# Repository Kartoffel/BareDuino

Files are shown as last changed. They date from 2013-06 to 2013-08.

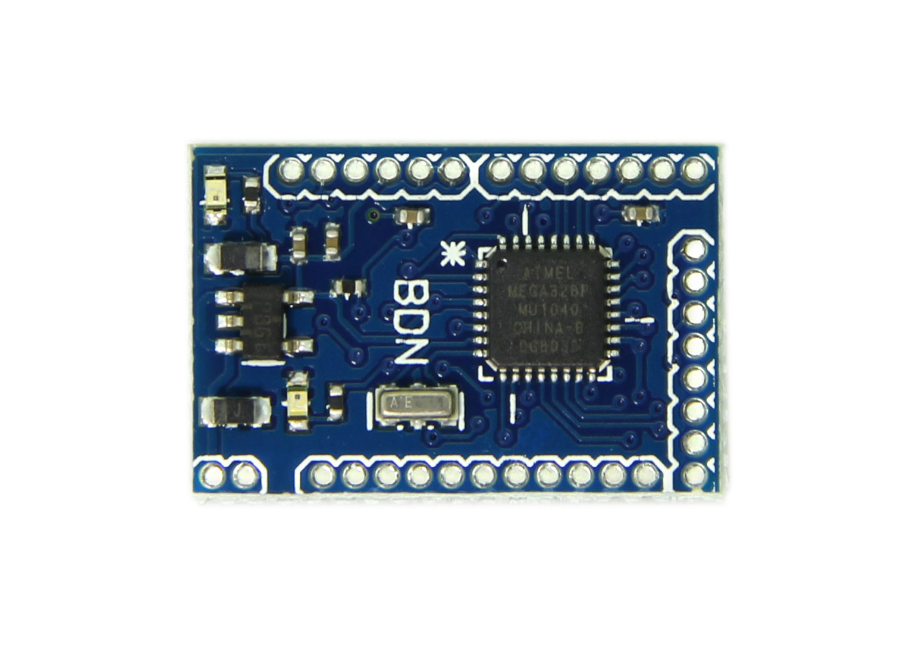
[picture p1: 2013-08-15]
Nano/pictures/IMG_1922.jpg

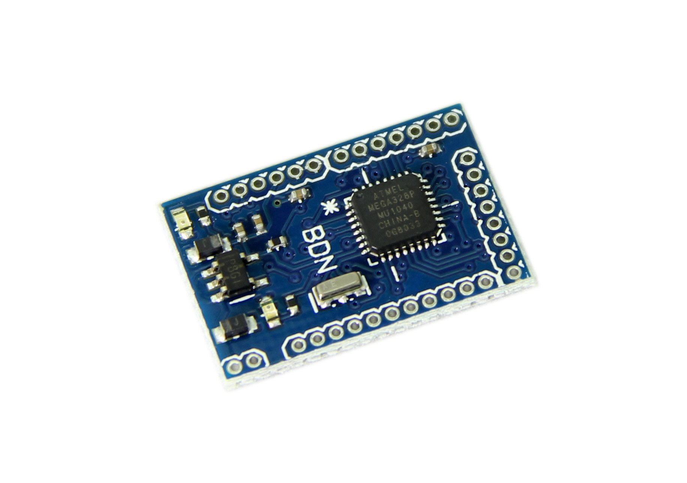
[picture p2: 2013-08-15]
Nano/pictures/IMG_1902.jpg

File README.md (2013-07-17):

BareDuino
===============
This repository contains the design (and other relevant) files for all the released BareDuino's.
Please visit this website for more information ----> http://www.niekproductions.com/

## License ##
All of the files in this repository are released under the BSD license.
Copyright (c) NiekProductions, 2013 All rights reserved.

Redistribution and use in source and binary forms, with or without modification, are permitted provided that the following conditions are met:
Redistributions of source code must retain the above copyright notice, this list of conditions and the following disclaimer. Redistributions in binary form must reproduce the above copyright notice, this list of conditions and the following disclaimer in the documentation and/or other materials provided with the distribution. THIS SOFTWARE IS PROVIDED BY THE COPYRIGHT HOLDERS AND CONTRIBUTORS "AS IS" AND ANY EXPRESS OR IMPLIED WARRANTIES, INCLUDING, BUT NOT LIMITED TO, THE IMPLIED WARRANTIES OF MERCHANTABILITY AND FITNESS FOR A PARTICULAR PURPOSE ARE DISCLAIMED. IN NO EVENT SHALL THE COPYRIGHT HOLDER OR CONTRIBUTORS BE LIABLE FOR ANY DIRECT, INDIRECT, INCIDENTAL, SPECIAL, EXEMPLARY, OR CONSEQUENTIAL DAMAGES (INCLUDING, BUT NOT LIMITED TO, PROCUREMENT OF SUBSTITUTE GOODS OR SERVICES; LOSS OF USE, DATA, OR PROFITS; OR BUSINESS INTERRUPTION) HOWEVER CAUSED AND ON ANY THEORY OF LIABILITY, WHETHER IN CONTRACT, STRICT LIABILITY, OR TORT (INCLUDING NEGLIGENCE OR OTHERWISE) ARISING IN ANY WAY OUT OF THE USE OF THIS SOFTWARE, EVEN IF ADVISED OF THE POSSIBILITY OF SUCH DAMAGE.

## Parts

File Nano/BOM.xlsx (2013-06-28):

BareDuino Nano v2 BOM
Prices are per item, bulk may be cheaper
Qty | Total Qty | Value | Device | Parts | Mouser Part# | Price per part | Total Price
4 | 4 | 0.1uF | C-EUC0402K | C1, C2, C3, C6 | 80-C0402C104K4P | $0.06 | $0.26
1 | 1 | 10K | R-EU_R0402 | R2 | 667-ERJ-2GEJ103X | $0.05 | $0.05
2 | 2 | 10uF | C-USC0603K | C4, C7 | 71-298D106X06R3M2T | $1.27 | $2.54
1 | 1 | 16Mhz | RESONATORSMD | Y1 | 81-CSTCE16M0V53-R0 | $0.93 | $0.93
2 | 2 | 330 | R-EU_R0402 | R1, R3 | 667-ERJ-2GEJ331X | $0.05 | $0.10
1 | 1 | ATMEGA328P-MU | ATMEGA328P-MU | UC1 | 556-ATMEGA328P-MU | $5.44 | $5.44
1 | 1 | Orange | LED0603 | LED2 | 720-LOQ976-PS-25 | $0.11 | $0.11
1 | 1 | Green | LED0603 | LED1 | 645-598-8070-107F | $0.09 | $0.09
1 | 1 | MIC5205 / other | V_REG_LDOSMD | U1 | 595-TPS76350DBVR | $1.02 | $1.02
Boards: | 1 |  |  |  | Total per board: |  | $10.54
 |  |  |  |  | Total excluding shipping: |  | $10.54
 |  |  |  |  | Shipping: |  | $0.00
 |  |  |  |  | Total: |  | $10.54

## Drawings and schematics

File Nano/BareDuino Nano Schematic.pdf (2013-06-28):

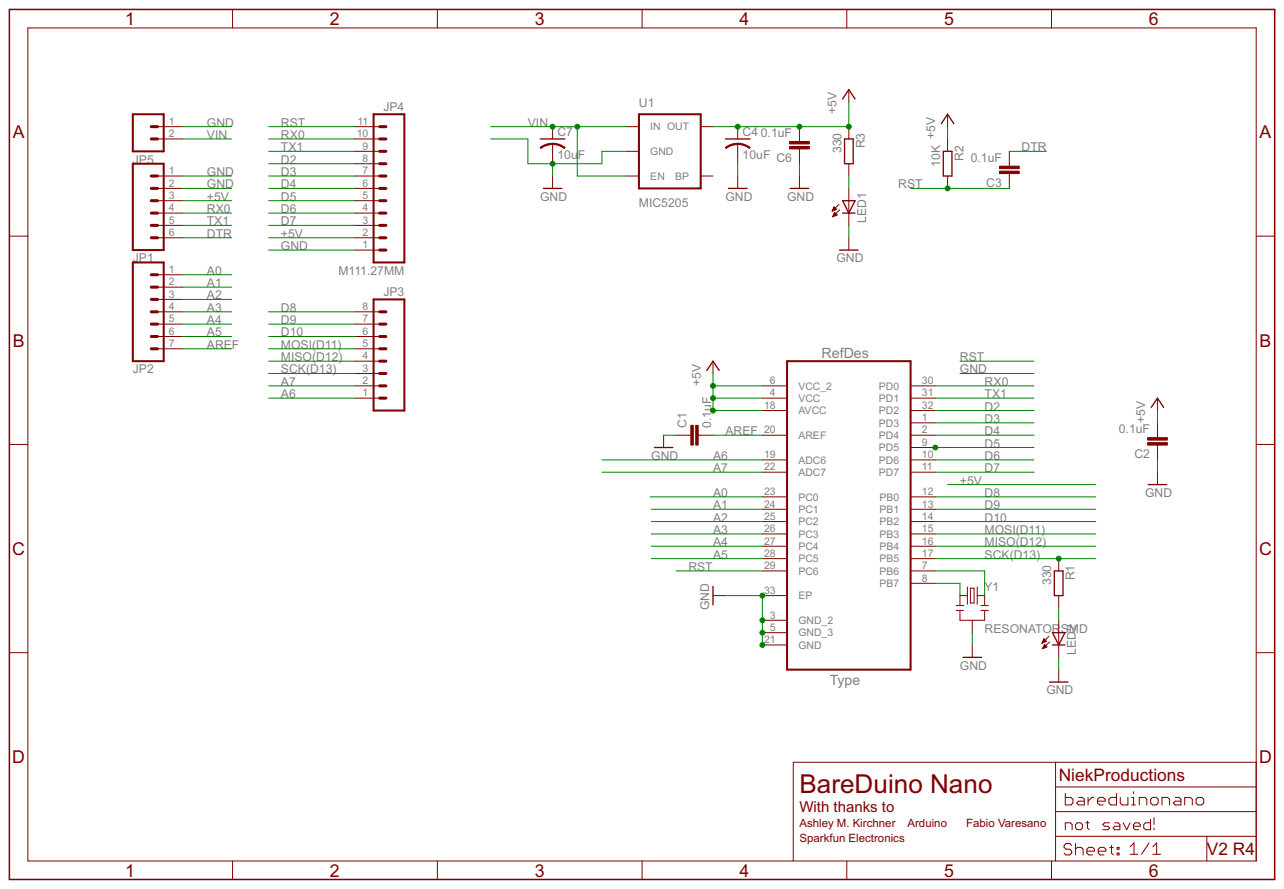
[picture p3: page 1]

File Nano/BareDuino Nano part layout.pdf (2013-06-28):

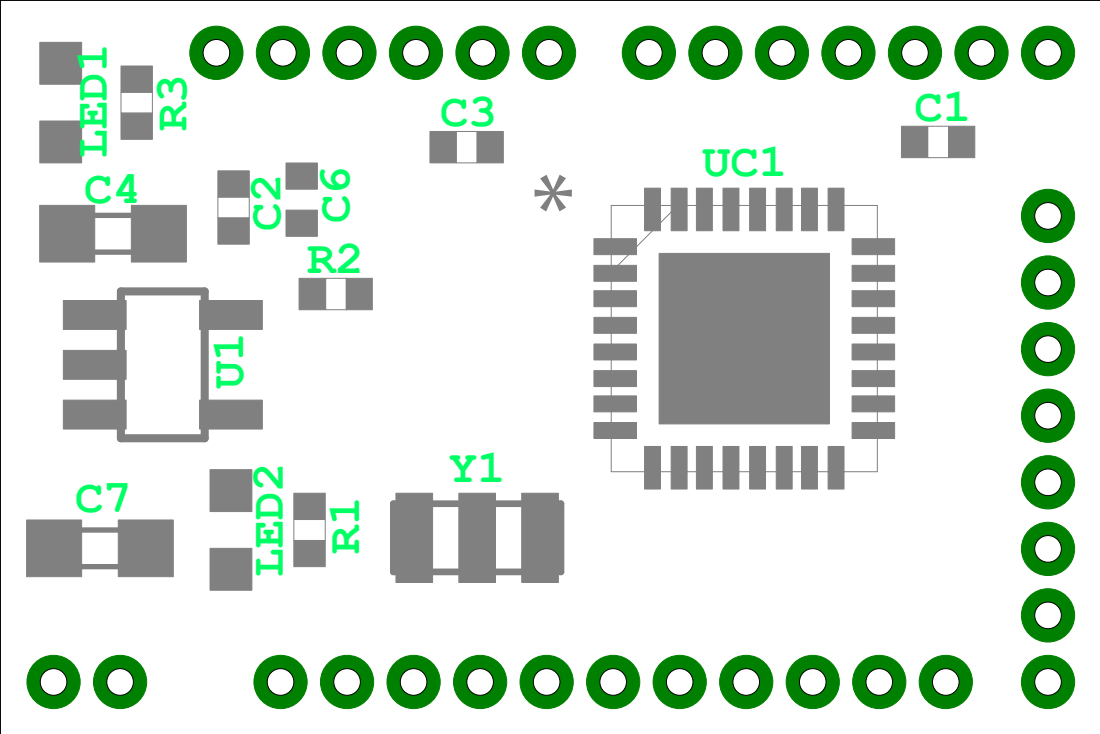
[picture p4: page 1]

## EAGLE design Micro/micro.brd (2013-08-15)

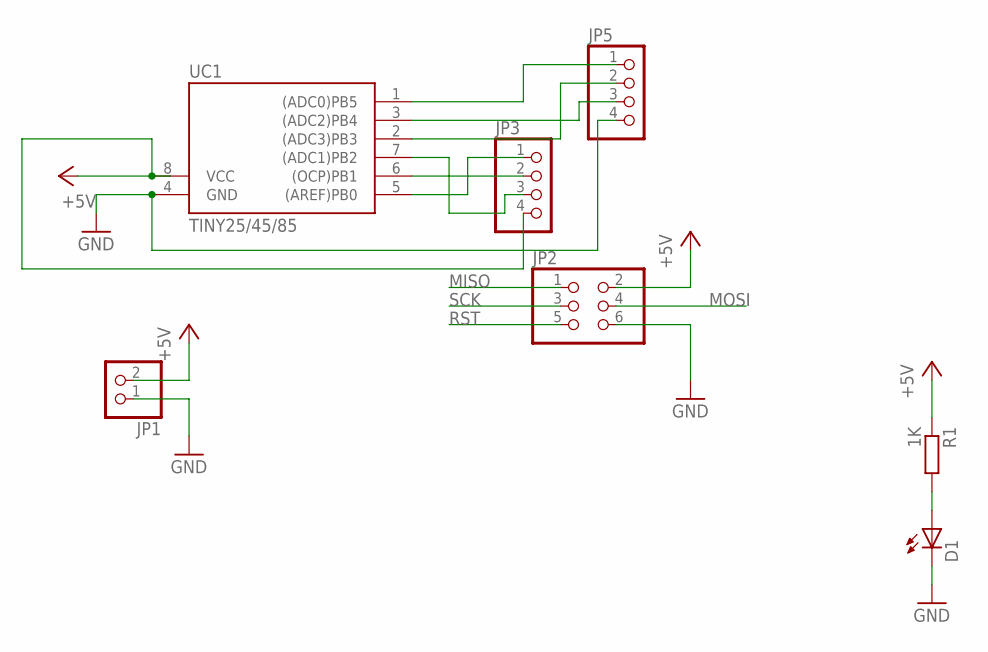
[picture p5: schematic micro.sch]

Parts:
D1: LED3MM
JP1: PINHD-1X02_2.54; 1X02
JP2: PINHD-2X03_2.54; 2X03
JP3, JP5: PINHD-1X4; 1X04
R1: 1K; 0207/2V
UC1: TINY25/45/85; SOIC8

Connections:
+5V: JP1.2, JP2.2, JP3.4, R1.1, UC1.8 (VCC)
GND: D1.K (C), JP1.1, JP2.6, JP5.4, UC1.4 (GND)
MISO: JP2.1, JP3.2, UC1.6 ((OCP)PB1)
MOSI: JP2.4, JP3.1, UC1.5 ((AREF)PB0)
unnamed: JP5.2, UC1.2 ((ADC3)PB3)
unnamed: JP5.3, UC1.3 ((ADC2)PB4)
unnamed: D1.A, R1.2
RST: JP2.5, JP5.1, UC1.1 ((ADC0)PB5)
SCK: JP2.3, JP3.3, UC1.7 ((ADC1)PB2)

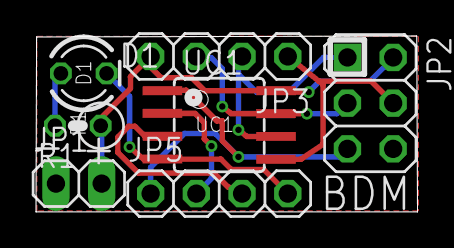
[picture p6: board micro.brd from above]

Board: 4 copper layers, 21.2 x 9.8 mm, 7 parts (0 on the bottom side), 9 nets.

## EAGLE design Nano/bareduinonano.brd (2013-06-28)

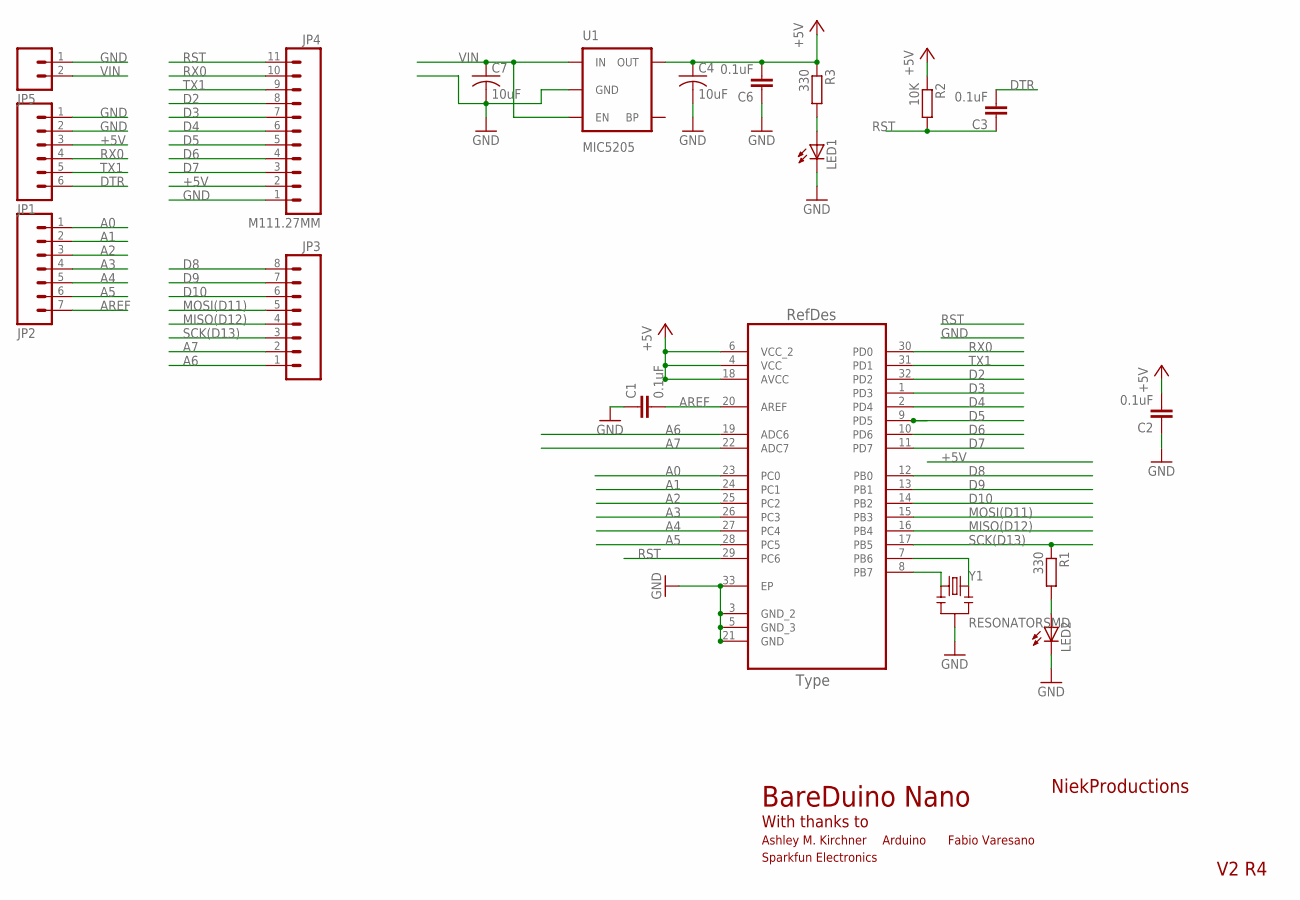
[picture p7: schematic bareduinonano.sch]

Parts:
C1, C2, C3, C6: 0.1uF; C0402K
C4, C7: 10uF; C0603K
JP1: M061.27MM; 1X06-1.27MM
JP2: M071.27MM; 1X07-1.27MM
JP3: M081.27MM; 1X08-1.27MM
JP4: M111.27MM; 1X11-1.27MM
JP5: M021.27MM; 1X02-1.27MM
LED1, LED2: LED0603; LED-0603
R1, R3: 330; R0402
R2: 10K; R0402
U1: MIC5205; SOT23-5
UC1: ATMEGA328P-MU; QFN50P500X500X100-33N
Y1: RESONATORSMD; RESONATOR-SMD

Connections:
+5V: C2.2, C4.1, C6.2, JP1.3, JP4.2, R2.1, R3.1, U1.5 (OUT), UC1.4 (VCC), UC1.6 (VCC_2), UC1.18 (AVCC)
A0: JP2.1, UC1.23 (PC0)
A1: JP2.2, UC1.24 (PC1)
A2: JP2.3, UC1.25 (PC2)
A3: JP2.4, UC1.26 (PC3)
A4: JP2.5, UC1.27 (PC4)
A5: JP2.6, UC1.28 (PC5)
A6: JP3.1, UC1.19 (ADC6)
A7: JP3.2, UC1.22 (ADC7)
AREF: C1.2, JP2.7, UC1.20 (AREF)
D2: JP4.8, UC1.32 (PD2)
D3: JP4.7, UC1.1 (PD3)
D4: JP4.6, UC1.2 (PD4)
D5: JP4.5, UC1.9 (PD5)
D6: JP4.4, UC1.10 (PD6)
D7: JP4.3, UC1.11 (PD7)
D8: JP3.8, UC1.12 (PB0)
D9: JP3.7, UC1.13 (PB1)
D10: JP3.6, UC1.14 (PB2)
DTR: C3.2, JP1.6
GND: C1.1, C2.1, C4.2, C6.1, C7.2, JP1.1, JP1.2, JP4.1, JP5.1, LED1.C, LED2.C, U1.2 (GND), UC1.3 (GND_2), UC1.5 (GND_3), UC1.21 (GND), UC1.33 (EP), Y1.2
MISO(D12): JP3.4, UC1.16 (PB4)
MOSI(D11): JP3.5, UC1.15 (PB3)
unnamed: UC1.8 (PB7), Y1.1
unnamed: LED2.A, R1.2
unnamed: UC1.7 (PB6), Y1.3
unnamed: LED1.A, R3.2
RST: C3.1, JP4.11, R2.2, UC1.29 (PC6)
RX0: JP1.4, JP4.10, UC1.30 (PD0)
SCK(D13): JP3.3, R1.1, UC1.17 (PB5)
TX1: JP1.5, JP4.9, UC1.31 (PD1)
VIN: C7.1, JP5.2, U1.1 (IN), U1.3 (EN)

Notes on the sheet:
BareDuino Nano
NiekProductions
V2 R4
With thanks to
Ashley M. Kirchner
Sparkfun Electronics
Arduino
Fabio Varesano

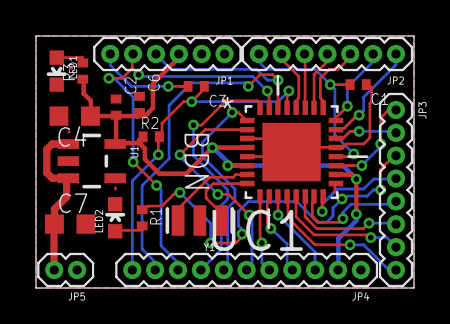
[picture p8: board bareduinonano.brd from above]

Board: 2 copper layers, 21.0 x 14.0 mm, 19 parts (0 on the bottom side), 32 nets.

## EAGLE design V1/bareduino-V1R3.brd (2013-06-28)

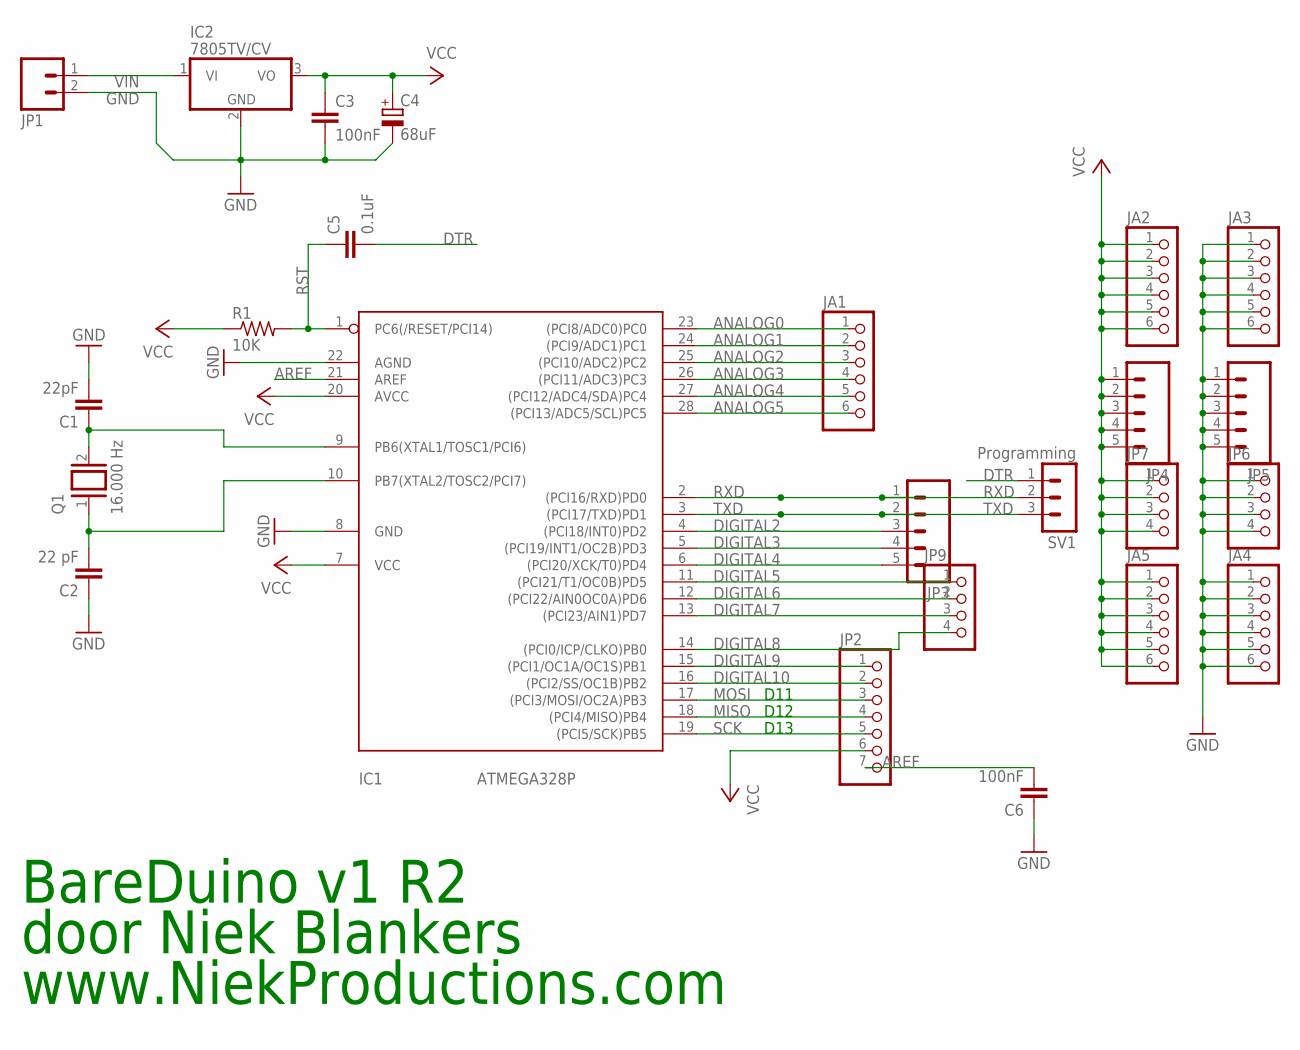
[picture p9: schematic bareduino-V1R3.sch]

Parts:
C1: 22pF; C025-024X044
C2: 22 pF; C025-024X044
C3: 100nF; C025-025X050
C4: 68uF; E2,5-6E
C5: 0.1uF; C025-024X044
C6: 100nF; C025-024X044
IC1: ATMEGA328P; DIL28/3
IC2: 7805TV/CV; TO220V
JA1, JA2, JA3, JA4, JA5: PINHD-1X6CB; 1X06-CLEANBIG
JP1: M025MM; SCREWTERMINAL-5MM-2
JP2: PINHD-1X07_2.54-S; 1X07-S
JP3, JP4, JP5: M05PTH; 1X05
JP6, JP7, JP9: PINHD-1X04_2.54-S; 1X04-S
Q1: 16.000 Hz; QS
R1: 10K; 0207/5V
SV1: Programming; MA03-1

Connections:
ANALOG0: IC1.23 ((PCI8/ADC0)PC0), JA1.1
ANALOG1: IC1.24 ((PCI9/ADC1)PC1), JA1.2
ANALOG2: IC1.25 ((PCI10/ADC2)PC2), JA1.3
ANALOG3: IC1.26 ((PCI11/ADC3)PC3), JA1.4
ANALOG4: IC1.27 ((PCI12/ADC4/SDA)PC4), JA1.5
ANALOG5: IC1.28 ((PCI13/ADC5/SCL)PC5), JA1.6
AREF: C6.2, IC1.21 (AREF), JP2.7
DIGITAL2: IC1.4 ((PCI18/INT0)PD2), JP3.3
DIGITAL3: IC1.5 ((PCI19/INT1/OC2B)PD3), JP3.4
DIGITAL4: IC1.6 ((PCI20/XCK/T0)PD4), JP3.5
DIGITAL5: IC1.11 ((PCI21/T1/OC0B)PD5), JP9.1
DIGITAL6: IC1.12 ((PCI22/AIN0OC0A)PD6), JP9.2
DIGITAL7: IC1.13 ((PCI23/AIN1)PD7), JP9.3
DIGITAL8: IC1.14 ((PCI0/ICP/CLKO)PB0), JP9.4
DIGITAL9: IC1.15 ((PCI1/OC1A/OC1S)PB1), JP2.1
DIGITAL10: IC1.16 ((PCI2/SS/OC1B)PB2), JP2.2
DTR: C5.2, SV1.1
GND: C1.2, C2.1, C3.2, C4.-, C6.1, IC1.8 (GND), IC1.22 (AGND), IC2.2 (GND), JA3.1, JA3.2, JA3.3, JA3.4, JA3.5, JA3.6, JA4.1, JA4.2, JA4.3, JA4.4, JA4.5, JA4.6, JP1.2, JP5.1, JP5.2, JP5.3, JP5.4, JP5.5, JP6.1, JP6.2, JP6.3, JP6.4
MISO: IC1.18 ((PCI4/MISO)PB4), JP2.4
MOSI: IC1.17 ((PCI3/MOSI/OC2A)PB3), JP2.3
unnamed: C2.2, IC1.10 (PB7(XTAL2/TOSC2/PCI7)), Q1.1
unnamed: C1.1, IC1.9 (PB6(XTAL1/TOSC1/PCI6)), Q1.2
RST: C5.1, IC1.1 (PC6(/RESET/PCI14)), R1.2
RXD: IC1.2 ((PCI16/RXD)PD0), JP3.1, SV1.2
SCK: IC1.19 ((PCI5/SCK)PB5), JP2.5
TXD: IC1.3 ((PCI17/TXD)PD1), JP3.2, SV1.3
VCC: C3.1, C4.+, IC1.7 (VCC), IC1.20 (AVCC), IC2.3 (VO), JA2.1, JA2.2, JA2.3, JA2.4, JA2.5, JA2.6, JA5.1, JA5.2, JA5.3, JA5.4, JA5.5, JA5.6, JP2.6, JP4.1, JP4.2, JP4.3, JP4.4, JP4.5, JP7.1, JP7.2, JP7.3, JP7.4, R1.1
VIN: IC2.1 (VI), JP1.1

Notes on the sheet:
D11
D12
D13
BareDuino v1 R2
door Niek Blankers
www.NiekProductions.com

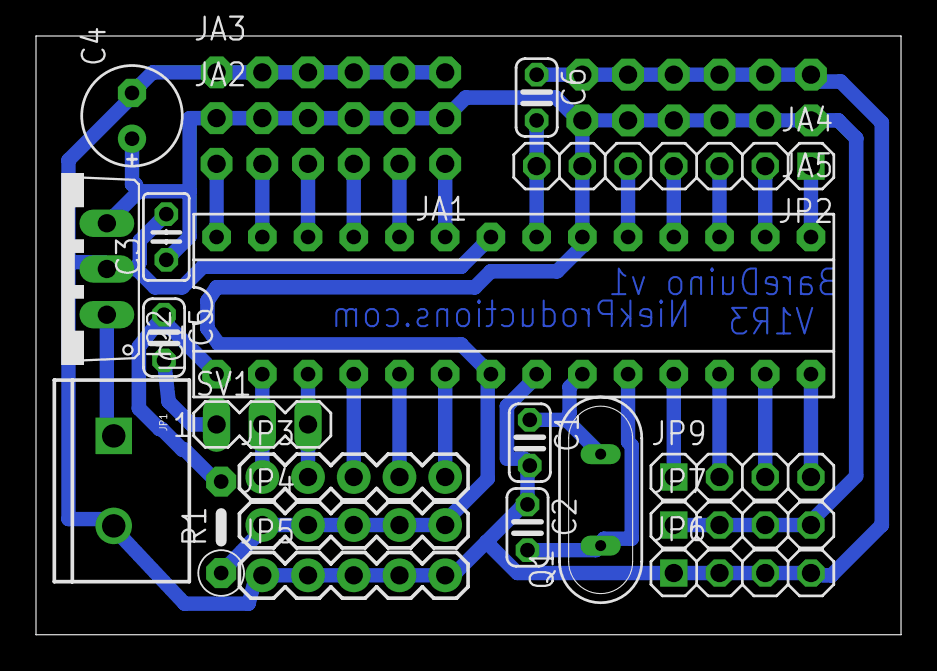
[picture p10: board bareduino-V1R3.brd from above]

Board: 2 copper layers, 48.1 x 33.3 mm, 24 parts (0 on the bottom side), 28 nets.

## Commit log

2013-06-28 Initial commit
    Contains the original bareduino, the bareduino nano and the bareduino
    micro.
    [BOM.xlsx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]
2013-08-15 Redrawn BareDuino Micro
    [micro v2.GBL, micro v2.GBO, micro v2.GBP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]
